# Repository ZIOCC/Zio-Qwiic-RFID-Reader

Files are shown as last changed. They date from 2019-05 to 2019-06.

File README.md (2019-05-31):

# Zio Qwiic RFID Reader (MFRC522)

> ###### About Zio
> Zio is a new line of open sourced, compact, and grid layout boards, fully integrated for Arduino and Qwiic ecosystem. Designed ideally for wearables, robotics, small-space limitations or other on the go projects. Check out other awesome Zio products [here](https://www.smart-prototyping.com/Zio)

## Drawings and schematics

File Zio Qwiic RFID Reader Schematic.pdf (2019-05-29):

## ANTENNA MATCHING CIRCUIT

A

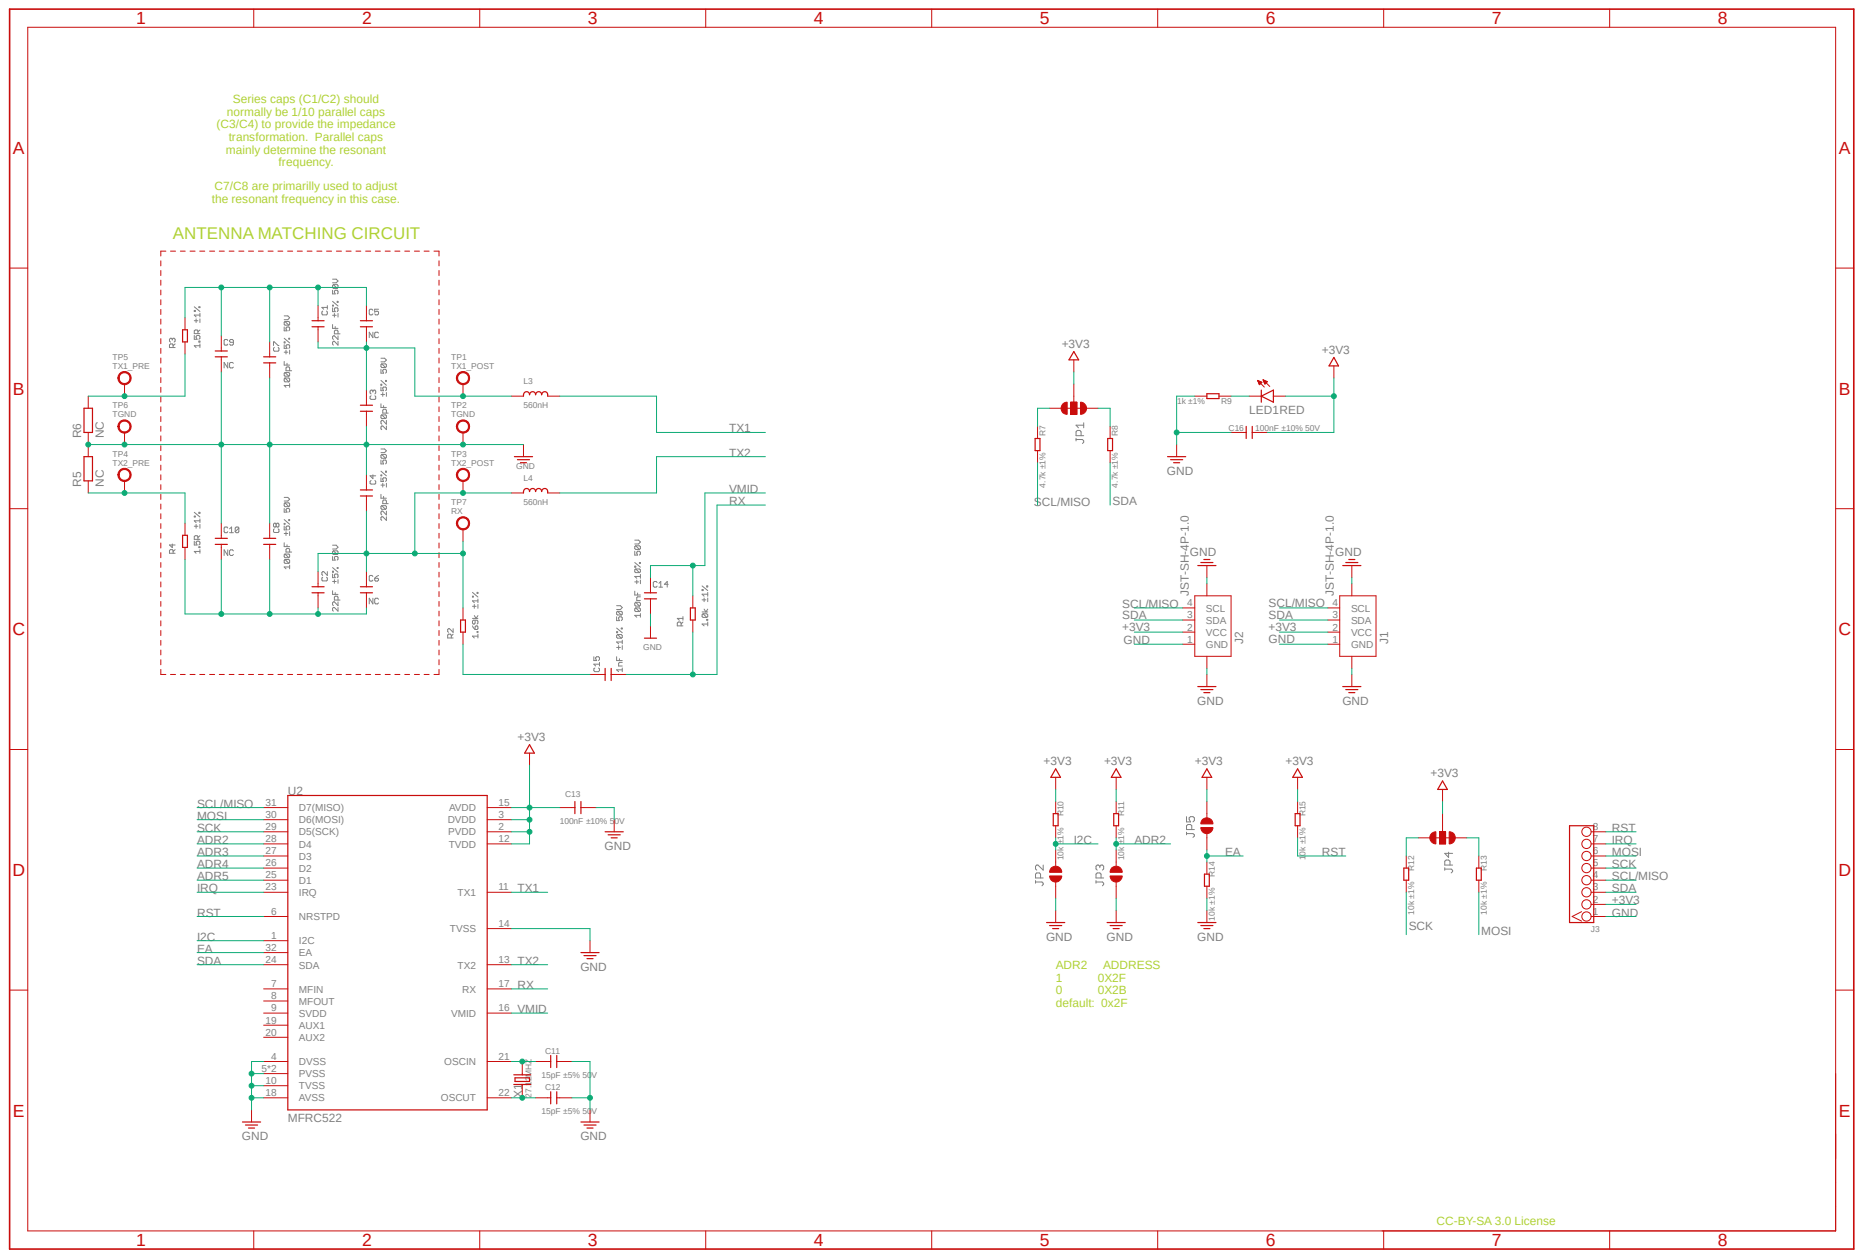
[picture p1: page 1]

Series caps (C1/C2) should
normally be 1/10 parallel caps
(C3/C4) to provide the impedance
transformation. Parallel caps
mainly determine the resonant

C7/C8 are primarilly used to adjust
the resonant frequency in this case.

CC-BY-SA 3.0 License

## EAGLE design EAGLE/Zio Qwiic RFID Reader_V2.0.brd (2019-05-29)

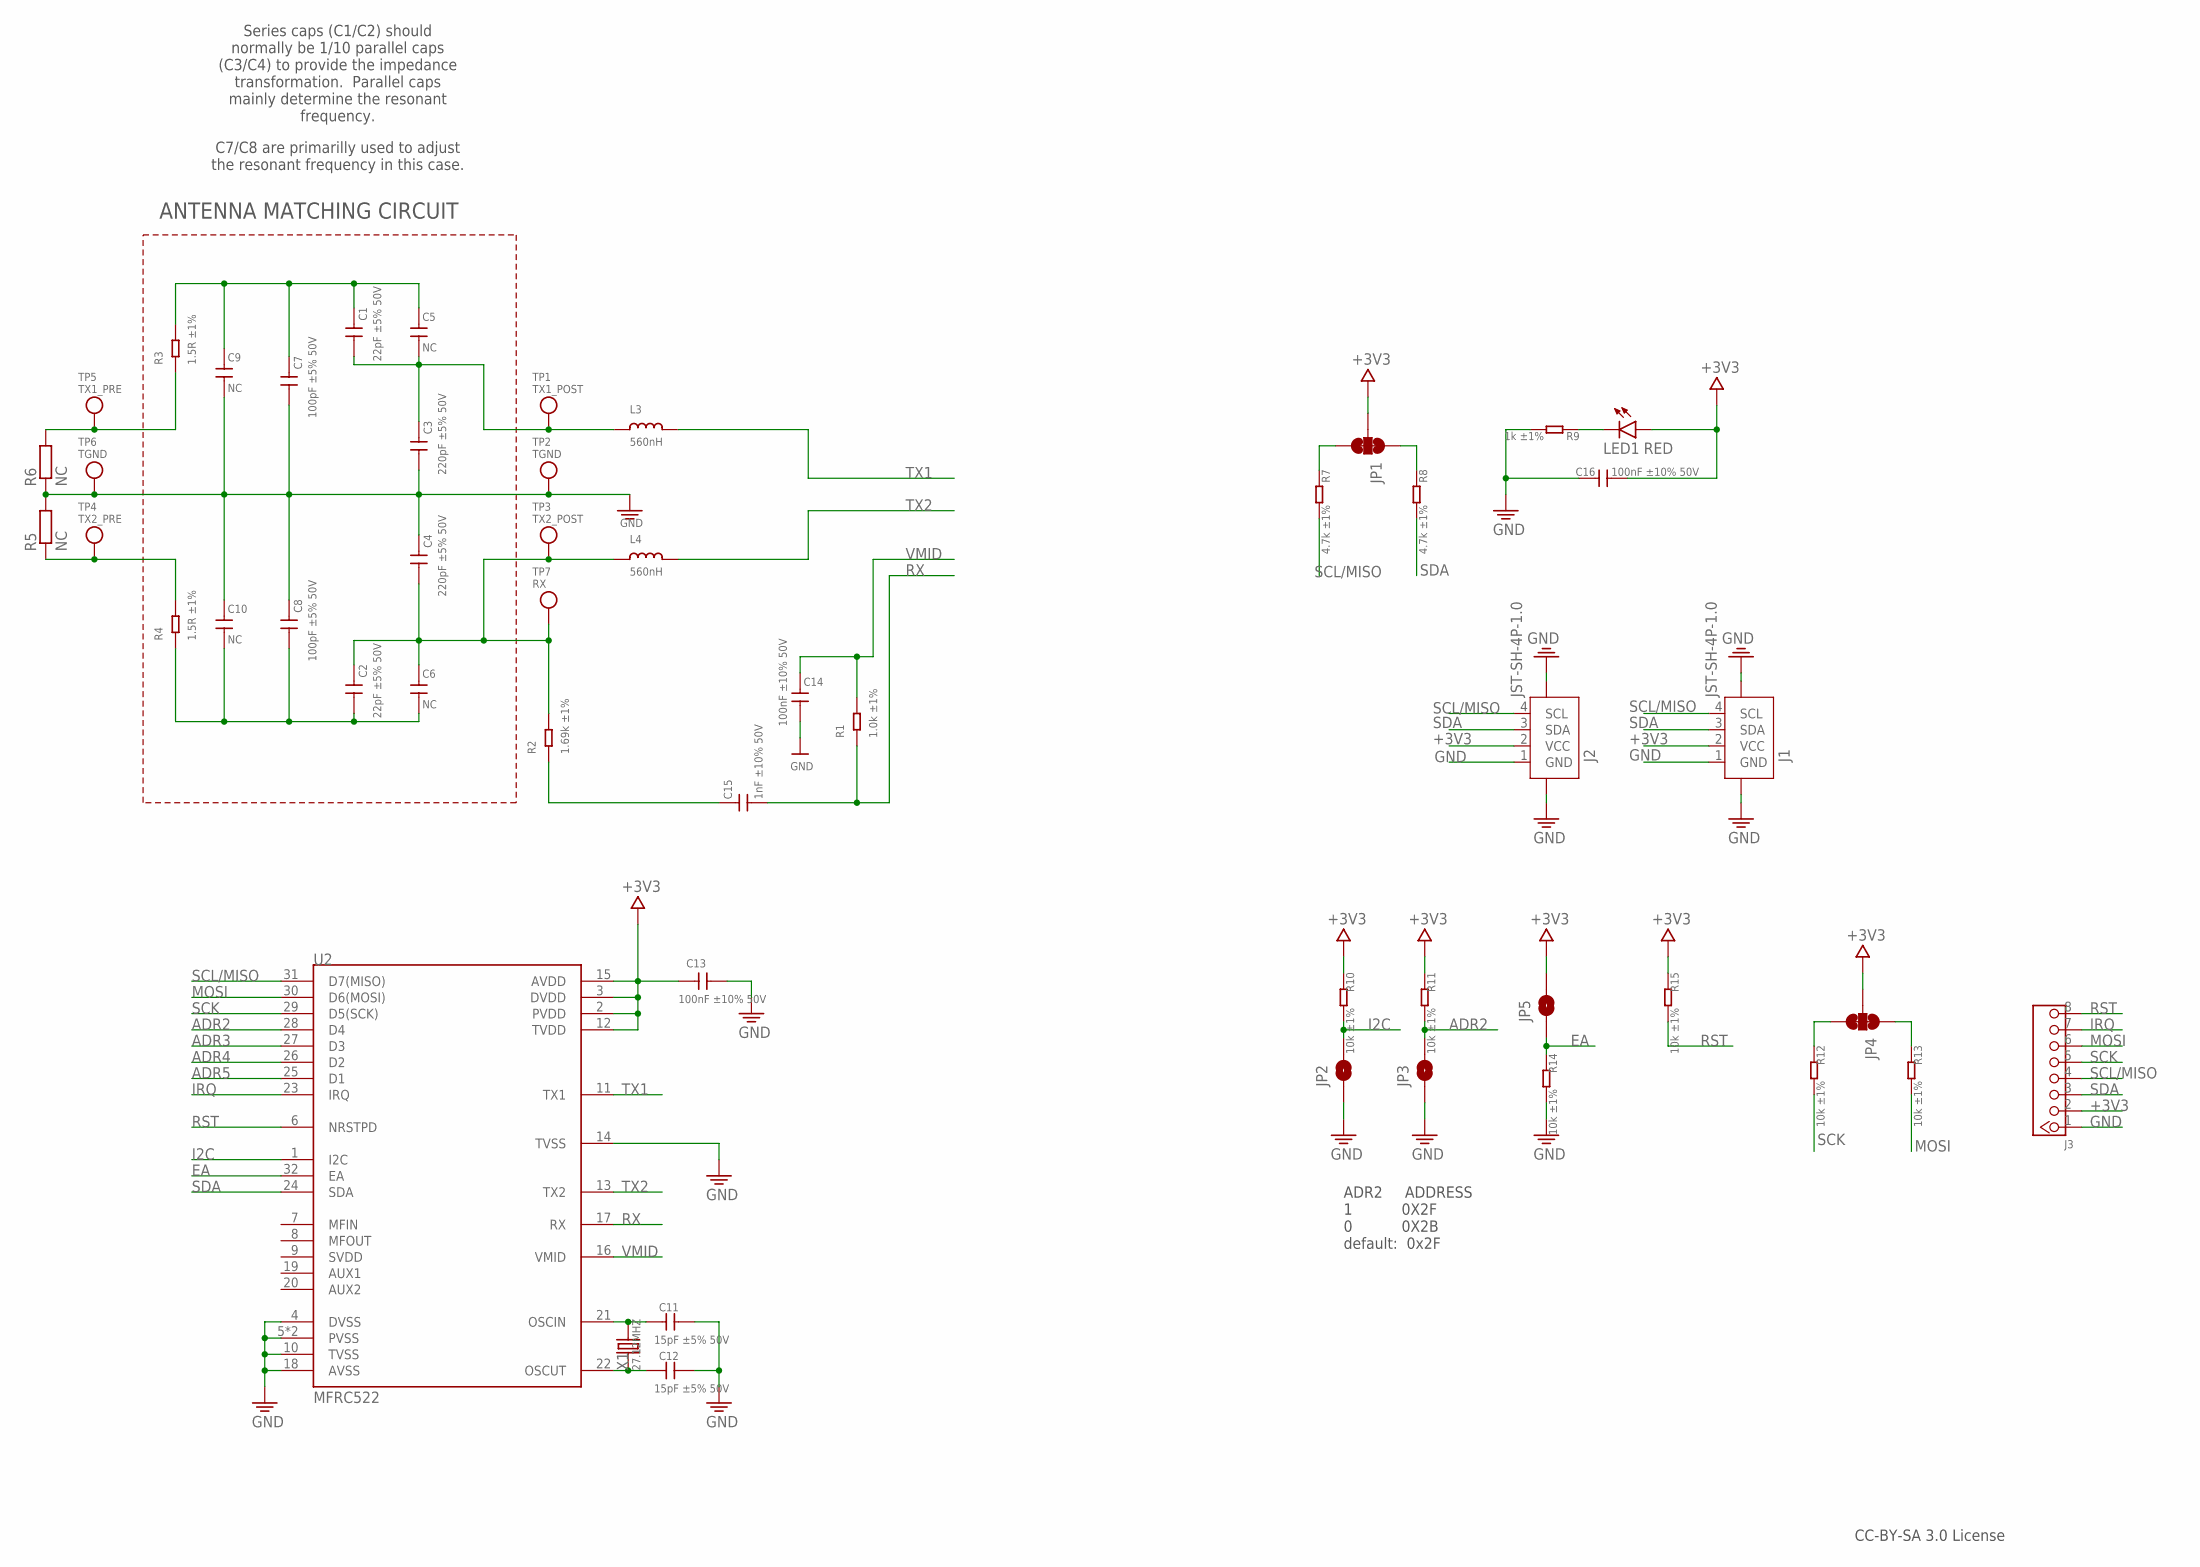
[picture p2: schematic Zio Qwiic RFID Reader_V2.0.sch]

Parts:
C1, C2: 22pF ±5% 50V; C0603
C3, C4: 220pF ±5% 50V; C0603
C5, C6, C9, C10: NC; C0603
C7, C8: 100pF ±5% 50V; C0603
C11, C12: 15pF ±5% 50V; C0603
C13, C14, C16: 100nF ±10% 50V; C0603
C15: 1nF ±10% 50V; C0603
J1, J2: JST-SH-4P-1.0; JST-SH-4P
J3: HEADER-8P-60/35MIL; 8P-2.54-60/35MIL
JP1, JP4: SMT-JUMPER_3_2-NC_TRACE
JP2, JP3, JP5: JUMPER-SMT_2_NC_PASTE_NOCREM; SMT-JUMPER_2_NC_PASTE_SILK_NOCREM
L3, L4: 560nH; 0805
LED1: RED; CHIP-LED0603
R1: 1.0k ±1%; R0603
R2: 1.69k ±1%; R0603
R3, R4: 1.5R ±1%; R0603
R5, R6: NC; R0201
R7, R8: 4.7k ±1%; R0603
R9: 1k ±1%; R0603
R10, R11, R12, R13, R14, R15: 10k ±1%; R0603
TP1: TX1_POST; TESTPOINT_ROUND_1MM
TP2, TP6: TGND; TESTPOINT_ROUND_1MM
TP3: TX2_POST; TESTPOINT_ROUND_1MM
TP4: TX2_PRE; TESTPOINT_ROUND_1MM
TP5: TX1_PRE; TESTPOINT_ROUND_1MM
TP7: RX; TESTPOINT_ROUND_1MM
U1: MFRC522; HVQFN32
X1: 27.12MHZ; HC49UP

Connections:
+3V3: C13.2, C16.2, J1.2 (VCC), J2.2 (VCC), J3.2, JP1.2, JP4.2, JP5.2, LED1.A, R10.1, R11.1, R15.1, U1.2 (PVDD), U1.3 (DVDD), U1.12 (TVDD), U1.15 (AVDD)
ADR2: JP3.2, R11.2, U1.28 (D4)
ADR3: U1.27 (D3)
ADR4: U1.26 (D2)
ADR5: U1.25 (D1)
EA: JP5.1, R14.1, U1.32 (EA)
GND: C3.2, C4.1, C7.2, C8.1, C9.2, C10.1, C11.1, C12.1, C13.1, C14.2, C16.1, J1.1 (GND), J1.NC1 (5), J1.NC2 (6), J2.1 (GND), J2.NC1 (5), J2.NC2 (6), J3.1, JP2.1, JP3.1, R5.2, R6.1, R9.2, R14.2, TP2.P$1, TP6.P$1, U1.4 (DVSS), U1.5 (PVSS), U1.10 (TVSS), U1.14 (TVSS), U1.18 (AVSS), U1.33 (PVSS)
I2C: JP2.2, R10.2, U1.1 (I2C)
IRQ: J3.7, U1.23 (IRQ)
MOSI: J3.6, R13.2, U1.30 (D6(MOSI))
unnamed: C12.2, U1.22 (OSCUT), X1.1
unnamed: C11.2, U1.21 (OSCIN), X1.2
unnamed: C1.2, C3.1, C5.2, L3.1, TP1.P$1
unnamed: R3.1, R6.2, TP5.P$1
unnamed: R4.2, R5.1, TP4.P$1
unnamed: JP1.3, R7.1
unnamed: C15.1, R2.1
unnamed: C2.1, C4.2, C6.1, L4.1, R2.2, TP3.P$1, TP7.P$1
unnamed: JP1.1, R8.1
unnamed: JP4.3, R12.1
unnamed: JP4.1, R13.1
unnamed: LED1.C, R9.1
RST: J3.8, R15.2, U1.6 (NRSTPD)
RX: C15.2, R1.1, U1.17 (RX)
SCK: J3.5, R12.2, U1.29 (D5(SCK))
SCL/MISO: J1.4 (SCL), J2.4 (SCL), J3.4, R7.2, U1.31 (D7(MISO))
SDA: J1.3 (SDA), J2.3 (SDA), J3.3, R8.2, U1.24 (SDA)
TX1: L3.2, U1.11 (TX1)
TX1_ANTENNA: C1.1, C5.1, C7.1, C9.1, R3.2
TX2: L4.2, U1.13 (TX2)
TX2_ANTENNA: C2.2, C6.2, C8.2, C10.2, R4.1
VMID: C14.1, R1.2, U1.16 (VMID)

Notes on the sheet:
ANTENNA MATCHING CIRCUIT
CC-BY-SA 3.0 License
Series caps (C1/C2) should normally be 1/10 parallel caps (C3/C4) to provide the impedance transformation. Parallel caps mainly determine the resonant frequency.
C7/C8 are primarilly used to adjust the resonant frequency in this case.
ADR2 ADDRESS 1 0X2F 0 0X2B default: 0x2F

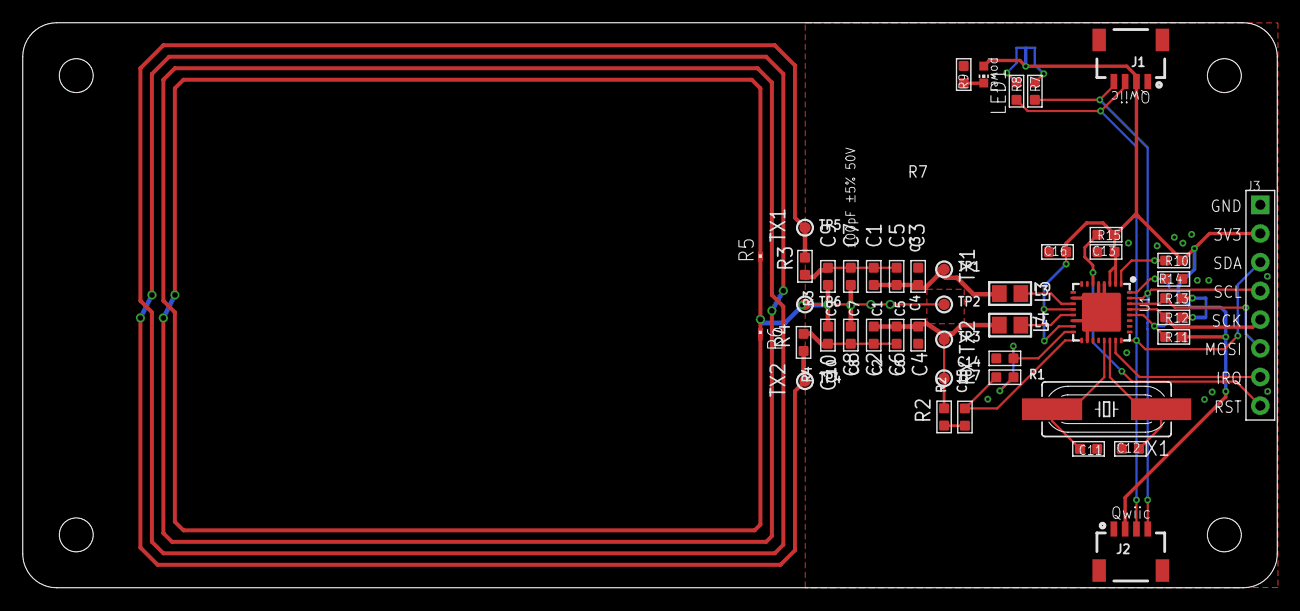
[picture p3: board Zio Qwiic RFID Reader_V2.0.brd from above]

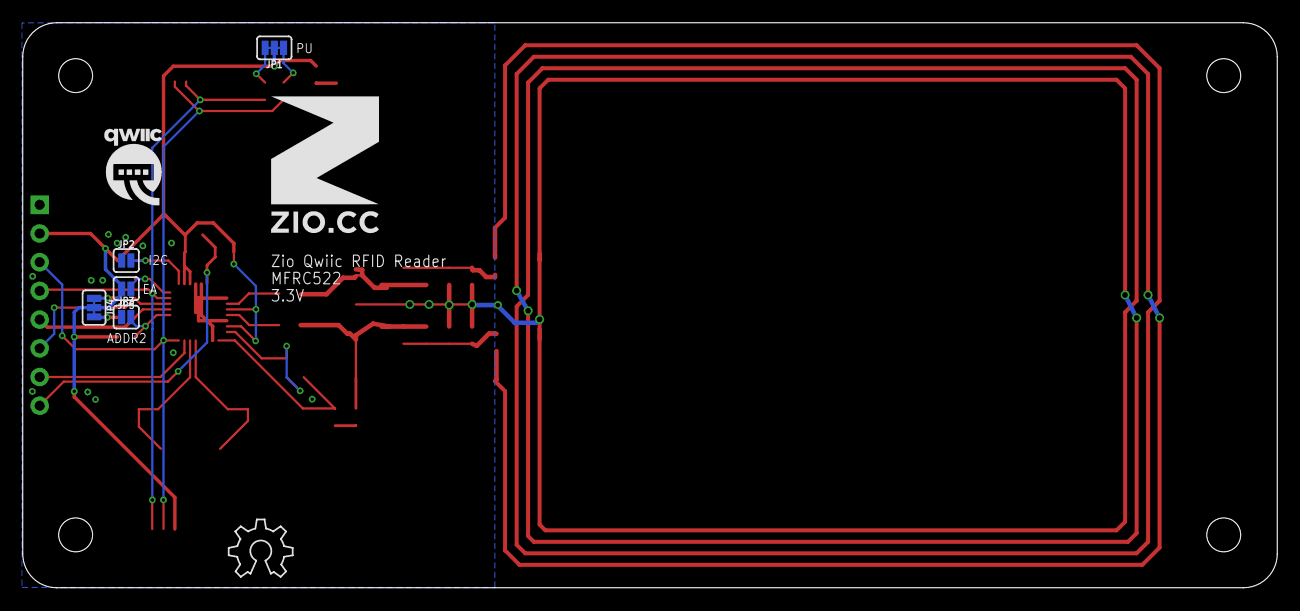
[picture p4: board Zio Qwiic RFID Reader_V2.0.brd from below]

Board: 2 copper layers, 111.0 x 50.0 mm, 54 parts (8 on the bottom side), 29 nets.

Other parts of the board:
U$7: 12MM
U$10: QWIIC-LOGO-MEDIUM
U$13: OSHW_6X200_NOTEXT

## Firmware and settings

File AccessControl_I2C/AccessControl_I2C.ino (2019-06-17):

#include <Wire.h>

#include "MFRC522_I2C.h"

#define SDA_PIN A4
#define SCL_PIN A5
#define RST_PIN 3

#include <EEPROM.h>     // We are going to read and write PICC's UIDs from/to EEPROM
//#include <MFRC522.h>  // Library for Mifare RC522 Devices

void ShowReaderDetails();
#define COMMON_ANODE

#ifdef COMMON_ANODE
#define LED_ON LOW
#define LED_OFF HIGH
#else
#define LED_ON HIGH
#define LED_OFF LOW
#endif

#define redLed 7    // Set Led Pins
#define greenLed 6
#define blueLed 5

#define relay 4     // Set Relay Pin
#define wipeB 3     // Button pin for WipeMode

bool programMode = false;  // initialize programming mode to false

uint8_t successRead;    // Variable integer to keep if we have Successful Read from Reader

byte storedCard[4];   // Stores an ID read from EEPROM
byte readCard[4];   // Stores scanned ID read from RFID Module
byte masterCard[4];   // Stores master card's ID read from EEPROM

MFRC522 mfrc522(0x2F);  // Create MFRC522 instance.

///////////////////////////////////////// Setup ///////////////////////////////////
void setup() {
  //Arduino Pin Configuration
  pinMode(redLed, OUTPUT);
  pinMode(greenLed, OUTPUT);
  pinMode(blueLed, OUTPUT);
  pinMode(wipeB, INPUT_PULLUP);   // Enable pin's pull up resistor
  pinMode(relay, OUTPUT);
  
  //Be careful how relay circuit behave on while resetting or power-cycling your Arduino
  digitalWrite(relay, HIGH);    // Make sure door is locked
  digitalWrite(redLed, LED_OFF);  // Make sure led is off
  digitalWrite(greenLed, LED_OFF);  // Make sure led is off
  digitalWrite(blueLed, LED_OFF); // Make sure led is off

  //Protocol Configuration
  Serial.begin(9600);  // Initialize serial communications with PC
  Wire.begin(); // Initialize I2C
  mfrc522.PCD_Init();    // Initialize MFRC522 Hardware

  Serial.println(F("Access Control Example v0.1"));   // For debugging purposes
  ShowReaderDetails();  // Show details of PCD - MFRC522 Card Reader details
  pinMode(13,OUTPUT);
  
  //Wipe Code - If the Button (wipeB) Pressed while setup run (powered on) it wipes EEPROM
  if (digitalRead(wipeB) == LOW) {  // when button pressed pin should get low, button connected to ground
    digitalWrite(redLed, LED_ON); // Red Led stays on to inform user we are going to wipe
    Serial.println(F("Wipe Button Pressed"));
    Serial.println(F("You have 10 seconds to Cancel"));
    Serial.println(F("This will be remove all records and cannot be undone"));
    bool buttonState = monitorWipeButton(10000); // Give user enough time to cancel operation
    if (buttonState == true && digitalRead(wipeB) == LOW) {    // If button still be pressed, wipe EEPROM
      Serial.println(F("Starting Wiping EEPROM"));
      for (uint16_t x = 0; x < EEPROM.length(); x = x + 1) {    //Loop end of EEPROM address
        if (EEPROM.read(x) == 0) {              //If EEPROM address 0
          // do nothing, already clear, go to the next address in order to save time and reduce writes to EEPROM
        }
        else {
          EEPROM.write(x, 0);       // if not write 0 to clear, it takes 3.3mS
        }
      }
      Serial.println(F("EEPROM Successfully Wiped"));
      digitalWrite(redLed, LED_OFF);  // visualize a successful wipe
      delay(200);
      digitalWrite(redLed, LED_ON);
      delay(200);
      digitalWrite(redLed, LED_OFF);
      delay(200);
      digitalWrite(redLed, LED_ON);
      delay(200);
      digitalWrite(redLed, LED_OFF);
    }
    else {
      Serial.println(F("Wiping Cancelled")); // Show some feedback that the wipe button did not pressed for 15 seconds
      digitalWrite(redLed, LED_OFF);
    }
  }
  // Check if master card defined, if not let user choose a master card
  // This also useful to just redefine the Master Card
  // You can keep other EEPROM records just write other than 143 to EEPROM address 1
  // EEPROM address 1 should hold magical number which is '143'
  if (EEPROM.read(1) != 143) {
    Serial.println(F("No Master Card Defined"));
    Serial.println(F("Scan A PICC to Define as Master Card"));
    do {
      successRead = getID();            // sets successRead to 1 when we get read from reader otherwise 0
      digitalWrite(blueLed, LED_ON);    // Visualize Master Card need to be defined
      delay(200);
      digitalWrite(blueLed, LED_OFF);
      delay(200);
    }
    while (!successRead);                  // Program will not go further while you not get a successful read
    for ( uint8_t j = 0; j < 4; j++ ) {        // Loop 4 times
      EEPROM.write( 2 + j, readCard[j] );  // Write scanned PICC's UID to EEPROM, start from address 3
    }
    EEPROM.write(1, 143);                  // Write to EEPROM we defined Master Card.
    Serial.println(F("Master Card Defined"));
  }
  Serial.println(F("-------------------"));
  Serial.println(F("Master Card's UID"));
  for ( uint8_t i = 0; i < 4; i++ ) {          // Read Master Card's UID from EEPROM
    masterCard[i] = EEPROM.read(2 + i);    // Write it to masterCard
    Serial.print(masterCard[i], HEX);
  }
  Serial.println("");
  Serial.println(F("-------------------"));
  Serial.println(F("Everything is ready"));
  Serial.println(F("Waiting PICCs to be scanned"));
  cycleLeds();    // Everything ready lets give user some feedback by cycling leds
}


///////////////////////////////////////// Main Loop ///////////////////////////////////
void loop () {
  do {
    successRead = getID();  // sets successRead to 1 when we get read from reader otherwise 0
    // When device is in use if wipe button pressed for 10 seconds initialize Master Card wiping
    if (digitalRead(wipeB) == LOW) { // Check if button is pressed
      // Visualize normal operation is iterrupted by pressing wipe button Red is like more Warning to user
      digitalWrite(redLed, LED_ON);  // Make sure led is off
      digitalWrite(greenLed, LED_OFF);  // Make sure led is off
      digitalWrite(blueLed, LED_OFF); // Make sure led is off
      // Give some feedback
      Serial.println(F("Wipe Button Pressed"));
      Serial.println(F("Master Card will be Erased! in 10 seconds"));
      bool buttonState = monitorWipeButton(10000); // Give user enough time to cancel operation
      if (buttonState == true && digitalRead(wipeB) == LOW) {    // If button still be pressed, wipe EEPROM
        EEPROM.write(1, 0);                  // Reset Magic Number.
        Serial.println(F("Master Card Erased from device"));
        Serial.println(F("Please reset to re-program Master Card"));
        while (1);
      }
      Serial.println(F("Master Card Erase Cancelled"));
    }
    if (programMode) {
      cycleLeds();              // Program Mode cycles through Red Green Blue waiting to read a new card
    }
    else {
      normalModeOn();     // Normal mode, blue Power LED is on, all others are off
    }
  }
  while (!successRead);   //the program will not go further while you are not getting a successful read
  if (programMode) {
    if ( isMaster(readCard) ) { //When in program mode check First If master card scanned again to exit program mode
      Serial.println(F("Master Card Scanned"));
      Serial.println(F("Exiting Program Mode"));
      Serial.println(F("-----------------------------"));
      programMode = false;
      return;
    }
    else {
      if ( findID(readCard) ) { // If scanned card is known delete it
        Serial.println(F("I know this PICC, removing..."));
        deleteID(readCard);
        Serial.println("-----------------------------");
        Serial.println(F("Scan a PICC to ADD or REMOVE to EEPROM"));
      }
      else {                    // If scanned card is not known add it
        Serial.println(F("I do not know this PICC, adding..."));
        writeID(readCard);
        Serial.println(F("-----------------------------"));
        Serial.println(F("Scan a PICC to ADD or REMOVE to EEPROM"));
      }
    }
  }
  else {
    if ( isMaster(readCard)) {    // If scanned card's ID matches Master Card's ID - enter program mode
      programMode = true;
      Serial.println(F("Hello Master - Entered Program Mode"));
      uint8_t count = EEPROM.read(0);   // Read the first Byte of EEPROM that
      Serial.print(F("I have "));     // stores the number of ID's in EEPROM
      Serial.print(count);
      Serial.print(F(" record(s) on EEPROM"));
      Serial.println("");
      Serial.println(F("Scan a PICC to ADD or REMOVE to EEPROM"));
      Serial.println(F("Scan Master Card again to Exit Program Mode"));
      Serial.println(F("-----------------------------"));
    }
    else {
      if ( findID(readCard) ) { // If not, see if the card is in the EEPROM
        Serial.println(F("Welcome, You shall pass"));
        granted(300);         // Open the door lock for 300 ms
      }
      else {      // If not, show that the ID was not valid
        Serial.println(F("You shall not pass"));
        denied();
      }
    }
  }
}

/////////////////////////////////////////  Access Granted    ///////////////////////////////////
void granted ( uint16_t setDelay) {
  digitalWrite(blueLed, LED_OFF);   // Turn off blue LED
  digitalWrite(redLed, LED_OFF);  // Turn off red LED
  digitalWrite(greenLed, LED_ON);   // Turn on green LED
  digitalWrite(relay, LOW);     // Unlock door!
  delay(setDelay);          // Hold door lock open for given seconds
  digitalWrite(relay, HIGH);    // Relock door
  delay(1000);            // Hold green LED on for a second
}

///////////////////////////////////////// Access Denied  ///////////////////////////////////
void denied() {
  digitalWrite(greenLed, LED_OFF);  // Make sure green LED is off
  digitalWrite(blueLed, LED_OFF);   // Make sure blue LED is off
  digitalWrite(redLed, LED_ON);   // Turn on red LED
  delay(1000);
}


///////////////////////////////////////// Get PICC's UID ///////////////////////////////////
uint8_t getID() {
  // Getting ready for Reading PICCs
  if ( ! mfrc522.PICC_IsNewCardPresent()) { //If a new PICC placed to RFID reader continue
    return 0;
  }
  if ( ! mfrc522.PICC_ReadCardSerial()) {   //Since a PICC placed get Serial and continue
    return 0;
  }
  // There are Mifare PICCs which have 4 byte or 7 byte UID care if you use 7 byte PICC
  // I think we should assume every PICC as they have 4 byte UID
  // Until we support 7 byte PICCs
  Serial.println(F("Scanned PICC's UID:"));
  for ( uint8_t i = 0; i < 4; i++) {  //
    readCard[i] = mfrc522.uid.uidByte[i];
    Serial.print(readCard[i], HEX);
  }
  Serial.println("");
  mfrc522.PICC_HaltA(); // Stop reading
  return 1;
}

void ShowReaderDetails() {
  // Get the MFRC522 software version
  byte v = mfrc522.PCD_ReadRegister(mfrc522.VersionReg);
  Serial.print(F("MFRC522 Software Version: 0x"));
  Serial.print(v, HEX);
  if (v == 0x91)
    Serial.print(F(" = v1.0"));
  else if (v == 0x92)
    Serial.print(F(" = v2.0"));
  else
    Serial.print(F(" (unknown),probably a chinese clone?"));
  Serial.println("");
  // When 0x00 or 0xFF is returned, communication probably failed
  if ((v == 0x00) || (v == 0xFF)) {
    Serial.println(F("WARNING: Communication failure, is the MFRC522 properly connected?"));
    Serial.println(F("SYSTEM HALTED: Check connections."));
    // Visualize system is halted
    digitalWrite(greenLed, LED_OFF);  // Make sure green LED is off
    digitalWrite(blueLed, LED_OFF);   // Make sure blue LED is off
    digitalWrite(redLed, LED_ON);   // Turn on red LED
    while (true); // do not go further
  }
}

///////////////////////////////////////// Cycle Leds (Program Mode) ///////////////////////////////////
void cycleLeds() {
  digitalWrite(redLed, LED_OFF);  // Make sure red LED is off
  digitalWrite(greenLed, LED_ON);   // Make sure green LED is on
  digitalWrite(blueLed, LED_OFF);   // Make sure blue LED is off
  delay(200);
  digitalWrite(redLed, LED_OFF);  // Make sure red LED is off
  digitalWrite(greenLed, LED_OFF);  // Make sure green LED is off
  digitalWrite(blueLed, LED_ON);  // Make sure blue LED is on
  delay(200);
  digitalWrite(redLed, LED_ON);   // Make sure red LED is on
  digitalWrite(greenLed, LED_OFF);  // Make sure green LED is off
  digitalWrite(blueLed, LED_OFF);   // Make sure blue LED is off
  delay(200);
}

//////////////////////////////////////// Normal Mode Led  ///////////////////////////////////
void normalModeOn () {
  digitalWrite(blueLed, LED_ON);  // Blue LED ON and ready to read card
  digitalWrite(redLed, LED_OFF);  // Make sure Red LED is off
  digitalWrite(greenLed, LED_OFF);  // Make sure Green LED is off
  digitalWrite(relay, HIGH);    // Make sure Door is Locked
}

//////////////////////////////////////// Read an ID from EEPROM //////////////////////////////
void readID( uint8_t number ) {
  uint8_t start = (number * 4 ) + 2;    // Figure out starting position
  for ( uint8_t i = 0; i < 4; i++ ) {     // Loop 4 times to get the 4 Bytes
    storedCard[i] = EEPROM.read(start + i);   // Assign values read from EEPROM to array
  }
}

///////////////////////////////////////// Add ID to EEPROM   ///////////////////////////////////
void writeID( byte a[] ) {
  if ( !findID( a ) ) {     // Before we write to the EEPROM, check to see if we have seen this card before!
    uint8_t num = EEPROM.read(0);     // Get the numer of used spaces, position 0 stores the number of ID cards
    uint8_t start = ( num * 4 ) + 6;  // Figure out where the next slot starts
    num++;                // Increment the counter by one
    EEPROM.write( 0, num );     // Write the new count to the counter
    for ( uint8_t j = 0; j < 4; j++ ) {   // Loop 4 times
      EEPROM.write( start + j, a[j] );  // Write the array values to EEPROM in the right position
    }
    successWrite();
    Serial.println(F("Succesfully added ID record to EEPROM"));
  }
  else {
    failedWrite();
    Serial.println(F("Failed! There is something wrong with ID or bad EEPROM"));
  }
}

///////////////////////////////////////// Remove ID from EEPROM   ///////////////////////////////////
void deleteID( byte a[] ) {
  if ( !findID( a ) ) {     // Before we delete from the EEPROM, check to see if we have this card!
    failedWrite();      // If not
    Serial.println(F("Failed! There is something wrong with ID or bad EEPROM"));
  }
  else {
    uint8_t num = EEPROM.read(0);   // Get the numer of used spaces, position 0 stores the number of ID cards
    uint8_t slot;       // Figure out the slot number of the card
    uint8_t start;      // = ( num * 4 ) + 6; // Figure out where the next slot starts
    uint8_t looping;    // The number of times the loop repeats
    uint8_t j;
    uint8_t count = EEPROM.read(0); // Read the first Byte of EEPROM that stores number of cards
    slot = findIDSLOT( a );   // Figure out the slot number of the card to delete
    start = (slot * 4) + 2;
    looping = ((num - slot) * 4);
    num--;      // Decrement the counter by one
    EEPROM.write( 0, num );   // Write the new count to the counter
    for ( j = 0; j < looping; j++ ) {         // Loop the card shift times
      EEPROM.write( start + j, EEPROM.read(start + 4 + j));   // Shift the array values to 4 places earlier in the EEPROM
    }
    for ( uint8_t k = 0; k < 4; k++ ) {         // Shifting loop
      EEPROM.write( start + j + k, 0);
    }
    successDelete();
    Serial.println(F("Succesfully removed ID record from EEPROM"));
  }
}

///////////////////////////////////////// Check Bytes   ///////////////////////////////////
bool checkTwo ( byte a[], byte b[] ) {   
  for ( uint8_t k = 0; k < 4; k++ ) {   // Loop 4 times
    if ( a[k] != b[k] ) {     // IF a != b then false, because: one fails, all fail
       return false;
    }
  }
  return true;  
}

///////////////////////////////////////// Find Slot   ///////////////////////////////////
uint8_t findIDSLOT( byte find[] ) {
  uint8_t count = EEPROM.read(0);       // Read the first Byte of EEPROM that
  for ( uint8_t i = 1; i <= count; i++ ) {    // Loop once for each EEPROM entry
    readID(i);                // Read an ID from EEPROM, it is stored in storedCard[4]
    if ( checkTwo( find, storedCard ) ) {   // Check to see if the storedCard read from EEPROM
      // is the same as the find[] ID card passed
      return i;         // The slot number of the card
    }
  }
}

///////////////////////////////////////// Find ID From EEPROM   ///////////////////////////////////
bool findID( byte find[] ) {
  uint8_t count = EEPROM.read(0);     // Read the first Byte of EEPROM that
  for ( uint8_t i = 1; i < count; i++ ) {    // Loop once for each EEPROM entry
    readID(i);          // Read an ID from EEPROM, it is stored in storedCard[4]
    if ( checkTwo( find, storedCard ) ) {   // Check to see if the storedCard read from EEPROM
      return true;
    }
    else {    // If not, return false
    }
  }
  return false;
}

///////////////////////////////////////// Write Success to EEPROM   ///////////////////////////////////
// Flashes the green LED 3 times to indicate a successful write to EEPROM
void successWrite() {
  digitalWrite(blueLed, LED_OFF);   // Make sure blue LED is off
  digitalWrite(redLed, LED_OFF);  // Make sure red LED is off
  digitalWrite(greenLed, LED_OFF);  // Make sure green LED is on
  delay(200);
  digitalWrite(greenLed, LED_ON);   // Make sure green LED is on
  delay(200);
  digitalWrite(greenLed, LED_OFF);  // Make sure green LED is off
  delay(200);
  digitalWrite(greenLed, LED_ON);   // Make sure green LED is on
  delay(200);
  digitalWrite(greenLed, LED_OFF);  // Make sure green LED is off
  delay(200);
  digitalWrite(greenLed, LED_ON);   // Make sure green LED is on
  delay(200);
}

///////////////////////////////////////// Write Failed to EEPROM   ///////////////////////////////////
// Flashes the red LED 3 times to indicate a failed write to EEPROM
void failedWrite() {
  digitalWrite(blueLed, LED_OFF);   // Make sure blue LED is off
  digitalWrite(redLed, LED_OFF);  // Make sure red LED is off
  digitalWrite(greenLed, LED_OFF);  // Make sure green LED is off
  delay(200);
  digitalWrite(redLed, LED_ON);   // Make sure red LED is on
  delay(200);
  digitalWrite(redLed, LED_OFF);  // Make sure red LED is off
  delay(200);
  digitalWrite(redLed, LED_ON);   // Make sure red LED is on
  delay(200);
  digitalWrite(redLed, LED_OFF);  // Make sure red LED is off
  delay(200);
  digitalWrite(redLed, LED_ON);   // Make sure red LED is on
  delay(200);
}

///////////////////////////////////////// Success Remove UID From EEPROM  ///////////////////////////////////
// Flashes the blue LED 3 times to indicate a success delete to EEPROM
void successDelete() {
  digitalWrite(blueLed, LED_OFF);   // Make sure blue LED is off
  digitalWrite(redLed, LED_OFF);  // Make sure red LED is off
  digitalWrite(greenLed, LED_OFF);  // Make sure green LED is off
  delay(200);
  digitalWrite(blueLed, LED_ON);  // Make sure blue LED is on
  delay(200);
  digitalWrite(blueLed, LED_OFF);   // Make sure blue LED is off
  delay(200);
  digitalWrite(blueLed, LED_ON);  // Make sure blue LED is on
  delay(200);
  digitalWrite(blueLed, LED_OFF);   // Make sure blue LED is off
  delay(200);
  digitalWrite(blueLed, LED_ON);  // Make sure blue LED is on
  delay(200);
}

////////////////////// Check readCard IF is masterCard   ///////////////////////////////////
// Check to see if the ID passed is the master programing card
bool isMaster( byte test[] ) {
  return checkTwo(test, masterCard);
}

bool monitorWipeButton(uint32_t interval) {
  uint32_t now = (uint32_t)millis();
  while ((uint32_t)millis() - now < interval)  {
    // check on every half a second
    if (((uint32_t)millis() % 500) == 0) {
      if (digitalRead(wipeB) != LOW)
        return false;
    }
  }
  return true;
}
